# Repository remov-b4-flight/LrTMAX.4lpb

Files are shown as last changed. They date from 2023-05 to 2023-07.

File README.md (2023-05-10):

# LrTMAX.4lpb
KiCAD project of LrTMAX Print Circuit Board  
project impeoved by versions, currently 3 versions are there.  
## MicroB
It's basic functionality of LrTMAX board.  
connected to host PC with USB micro B connector.  
## type C
It changed host connectors with USB type C.  
## DFU
Add ability to use DFU bootloader by set BOOT0 signal by DIP switch.  
(No needed ST-LIMK for firmware load, use STM32programmer.)  
and changed ST-LINK connector assignment to STDC-14. (STLiNKV3-MINIE compatible)

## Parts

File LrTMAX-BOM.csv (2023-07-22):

Ref | Qnty | Value | Cmp name | Footprint
C10, C11, C12, C13, C14, C15, C16, C17, C18, C19, C20, C21, C22, C23, C24, C25, | 16 | 33n | C-Device | Capacitor_SMD:C_0805_2012Metric
C30, C31, C32, C33, C34, C35, C36, C37, C38, C55, | 10 | 100n | C-Device | Capacitor_SMD:C_0805_2012Metric
C40, C41, C43, C44, C45, | 5 | 100n | C-Device | Capacitor_SMD:C_0603_1608Metric
C42, C46, C51, C52, | 4 | 4.7u | C-Device | Capacitor_SMD:C_0805_2012Metric
C47, C48, C49, C50, C53, C54, C56, | 7 | 1u | C-Device | Capacitor_SMD:C_0805_2012Metric
D1, D2, D3, D4, D5, D6, D7, D8, D10, D11, D12, D13, D14, D15, D16, D17, | 16 | 1N4148W | 1N4148W-Diode | LrE-6:D_SOD-123
D18, | 1 | LED 0603 BLUE | LED-Device | LED_SMD:LED_0603_1608Metric
D31, D32, D33, D34, D35, D36, D37, D38, | 8 | WS2812B-2020 | WS2812B-2020 | LrE-6:LED_WS2812B-2020
J1, | 1 | USB_C_Receptacle_USB2.0 | USB_C_Receptacle_USB2.0 | Connector_USB:USB_C_Receptacle_HRO_TYPE-C-31-M-12
J2, | 1 | Conn_02x05_Odd_Even | Conn_02x05_Odd_Even | Connector_PinHeader_1.27mm:PinHeader_2x05_P1.27mm_Vertical
Q1, | 1 | 2N7002 | 2N7002-Transistor_FET | Package_TO_SOT_SMD:SOT-23
R1, R2, R3, R4, R42, | 5 | 1K | R-Device | Resistor_SMD:R_0805_2012Metric
R5, R6, | 2 | 5.1K | R-Device | Resistor_SMD:R_0805_2012Metric
R7, R10, R11, R12, R13, R14, R15, R16, R17, R18, R19, R20, R21, R22, R23, R24, R25, R40, R41, R47, | 20 | 10K | R-Device | Resistor_SMD:R_0805_2012Metric
R44, | 1 | 100 | R-Device | Resistor_SMD:R_0805_2012Metric
R45, | 1 | 62 | R-Device | Resistor_SMD:R_0805_2012Metric
R46, | 1 | 1.2K | R-Device | Resistor_SMD:R_0805_2012Metric
R48, | 1 | 470 | R-Device | Resistor_SMD:R_0805_2012Metric
SW1, SW2, SW3, SW4, SW5, SW6, SW7, SW8, | 8 | Tact_SW_8mm | SW_Push_45deg-Switch | Button_Switch_THT:SW_PUSH_6mm_H9.5mm
SW10, SW11, SW12, SW13, SW14, SW15, SW16, SW17, | 8 | EC11_SMD | Rotary_Encoder_Switch-Device | Rotary_Encoder:RotaryEncoder_Alps_EC11E-Switch_Vertical_H20mm
SW20, | 1 | SW_SPST | SW_SPST | Button_Switch_SMD:SW_DIP_SPSTx01_Slide_Copal_CHS-01B_W7.62mm_P1.27mm
TP1, | 1 | TestPoint | TestPoint-Connector | TestPoint:TestPoint_THTPad_D1.0mm_Drill0.5mm
U1, | 1 | STM32F072C8Tx | STM32F072C8Tx-MCU_ST_STM32F0 | Package_QFP:LQFP-48_7x7mm_P0.5mm
U3, | 1 | SSD1306_OLED_0.91 | OLED-0.91 | LrE-6:OLED-9.1
U4, | 1 | SPX3819M5-L3-3TR | LDK130-08_SOT23_SOT353-Regulator_Linear | Package_TO_SOT_SMD:SOT-23-5

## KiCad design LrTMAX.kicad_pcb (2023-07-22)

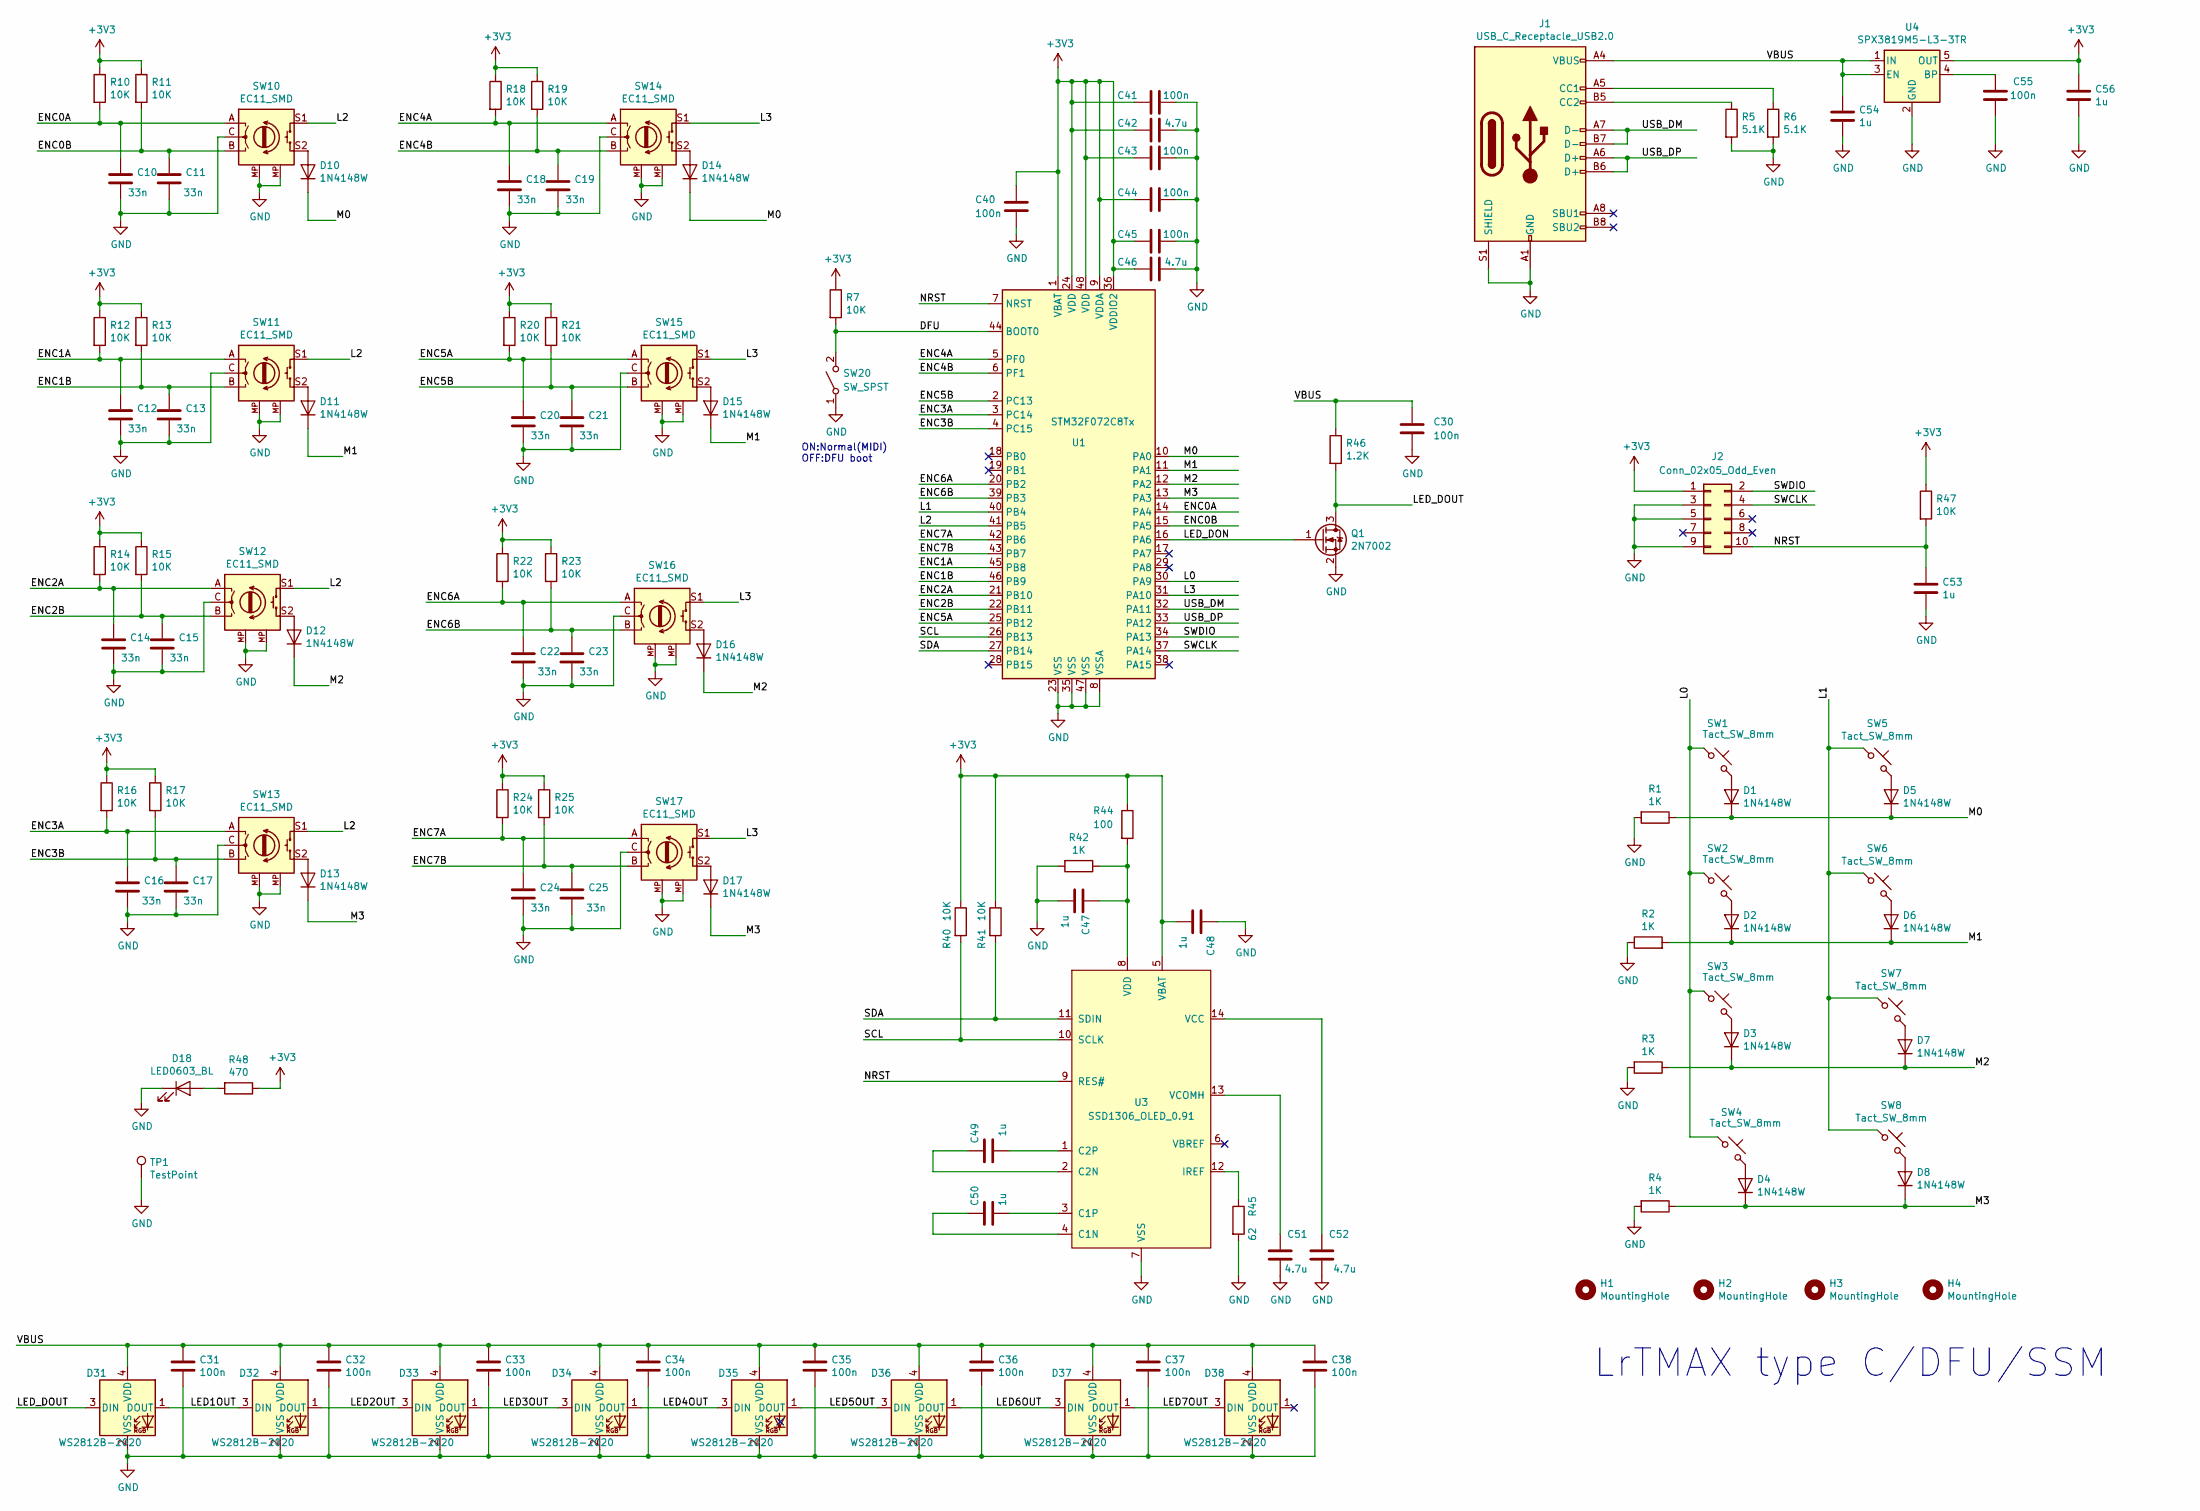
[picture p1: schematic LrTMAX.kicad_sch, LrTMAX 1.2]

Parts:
C10, C11, C12, C13, C14, C15, C16, C17, C18, C19, C20, C21, C22, C23, C24, C25: 33n; C_0805_2012Metric
C30, C31, C32, C33, C34, C35, C36, C37, C38, C55: 100n; C_0805_2012Metric
C40, C41, C43, C44, C45: 100n; C_0603_1608Metric
C42, C46, C51, C52: 4.7u; C_0805_2012Metric
C47, C48, C49, C50, C53, C54, C56: 1u; C_0805_2012Metric
D1, D2, D3, D4, D5, D6, D7, D8, D10, D11, D12, D13, D14, D15, D16, D17: 1N4148W; D_SOD-123
D18: LED0603_BL; LED_0603_1608Metric
D31, D32, D33, D34, D35, D36, D37, D38: WS2812B-2020; LED_WS2812B-2020
H1, H2, H3, H4: MountingHole; MountingHole_2.7mm_M2.5
J1: USB_C_Receptacle_USB2.0; USB_C_Receptacle_HRO_TYPE-C-31-M-12
J2: Conn_02x05_Odd_Even; PinHeader_2x05_P1.27mm_Vertical
Q1: 2N7002; SOT-23
R1, R2, R3, R4, R42: 1K; R_0805_2012Metric
R5, R6: 5.1K; R_0805_2012Metric
R7, R10, R11, R12, R13, R14, R15, R16, R17, R18, R19, R20, R21, R22, R23, R24, R25, R40, R41, R47: 10K; R_0805_2012Metric
R44: 100; R_0805_2012Metric
R45: 62; R_0805_2012Metric
R46: 1.2K; R_0805_2012Metric
R48: 470; R_0805_2012Metric
SW1, SW2, SW3, SW4, SW5, SW6, SW7, SW8: Tact_SW_8mm; SW_PUSH_6mm_H9.5mm
SW10, SW11, SW12, SW13, SW14, SW15, SW16, SW17: EC11_SMD; RotaryEncoder_Alps_EC11E-Switch_Vertical_H20mm
SW20: SW_SPST; SW_DIP_SPSTx01_Slide_Copal_CHS-01B_W7.62mm_P1.27mm
TP1: TestPoint; TestPoint_THTPad_D1.0mm_Drill0.5mm
U1: STM32F072C8Tx; LQFP-48_7x7mm_P0.5mm
U3: SSD1306_OLED_0.91; OLED-9.1
U4: SPX3819M5-L3-3TR; SOT-23-5

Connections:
+3V3: C40.1, C41.2, C42.2, C43.2, C44.2, C45.2, C46.2, C48.1, C56.1, J2.1, R7.1, R10.1, R11.1, R12.1, R13.1, R14.1, R15.1, R16.1, R17.1, R18.1, R19.1, R20.1, R21.1, R22.1, R23.1, R24.1, R25.1, R40.1, R41.1, R44.1, R47.1, R48.1, U1.1 (VBAT), U1.9 (VDDA), U1.24 (VDD), U1.36 (VDDIO2), U1.48 (VDD), U3.5 (VBAT), U4.5 (OUT)
/DFU: R7.2, SW20.2 (B), U1.44 (BOOT0)
/ENC0A: C10.1, R10.2, SW10.A, U1.14 (PA4)
/ENC0B: C11.1, R11.2, SW10.B, U1.15 (PA5)
/ENC1A: C12.1, R12.2, SW11.A, U1.45 (PB8)
/ENC1B: C13.1, R13.2, SW11.B, U1.46 (PB9)
/ENC2A: C14.1, R14.2, SW12.A, U1.21 (PB10)
/ENC2B: C15.1, R15.2, SW12.B, U1.22 (PB11)
/ENC3A: C16.1, R16.2, SW13.A, U1.3 (PC14)
/ENC3B: C17.1, R17.2, SW13.B, U1.4 (PC15)
/ENC4A: C18.1, R18.2, SW14.A, U1.5 (PF0)
/ENC4B: C19.1, R19.2, SW14.B, U1.6 (PF1)
/ENC5A: C20.1, R20.2, SW15.A, U1.25 (PB12)
/ENC5B: C21.1, R21.2, SW15.B, U1.2 (PC13)
/ENC6A: C22.1, R22.2, SW16.A, U1.20 (PB2)
/ENC6B: C23.1, R23.2, SW16.B, U1.39 (PB3)
/ENC7A: C24.1, R24.2, SW17.A, U1.42 (PB6)
/ENC7B: C25.1, R25.2, SW17.B, U1.43 (PB7)
/L0: SW1.1, SW2.1, SW3.1, SW4.1, U1.30 (PA9)
/L1: SW5.1, SW6.1, SW7.1, SW8.1, U1.40 (PB4)
/L2: SW10.S1, SW11.S1, SW12.S1, SW13.S1, U1.41 (PB5)
/L3: SW14.S1, SW15.S1, SW16.S1, SW17.S1, U1.31 (PA10)
/LED1OUT: D31.1 (DOUT), D32.3 (DIN)
/LED2OUT: D32.1 (DOUT), D33.3 (DIN)
/LED3OUT: D33.1 (DOUT), D34.3 (DIN)
/LED4OUT: D34.1 (DOUT), D35.3 (DIN)
/LED5OUT: D35.1 (DOUT), D36.3 (DIN)
/LED6OUT: D36.1 (DOUT), D37.3 (DIN)
/LED7OUT: D37.1 (DOUT), D38.3 (DIN)
/LED_DON: Q1.1 (G), U1.16 (PA6)
/LED_DOUT: D31.3 (DIN), Q1.3 (D), R46.2
/M0: D1.1 (K), D5.1 (K), D10.1 (K), D14.1 (K), R1.1, U1.10 (PA0)
/M1: D2.1 (K), D6.1 (K), D11.1 (K), D15.1 (K), R2.2, U1.11 (PA1)
/M2: D3.1 (K), D7.1 (K), D12.1 (K), D16.1 (K), R3.1, U1.12 (PA2)
/M3: D4.1 (K), D8.1 (K), D13.1 (K), D17.1 (K), R4.1, U1.13 (PA3)
/NRST: C53.1, J2.10, R47.2, U1.7 (NRST), U3.9 (RES#)
/SCL: R40.2, U1.26 (PB13), U3.10 (SCLK)
/SDA: R41.2, U1.27 (PB14), U3.11 (SDIN)
/SWCLK: J2.4, U1.37 (PA14)
/SWDIO: J2.2, U1.34 (PA13)
/USB_DM: J1.A7 (D-), J1.B7 (D-), U1.32 (PA11)
/USB_DP: J1.A6 (D+), J1.B6 (D+), U1.33 (PA12)
/VBUS: C30.1, C31.1, C32.1, C33.1, C34.1, C35.1, C36.1, C37.1, C38.1, C54.1, D31.4 (VDD), D32.4 (VDD), D33.4 (VDD), D34.4 (VDD), D35.4 (VDD), D36.4 (VDD), D37.4 (VDD), D38.4 (VDD), J1.A4 (VBUS), J1.A9 (VBUS), J1.B4 (VBUS), J1.B9 (VBUS), R46.1, U4.1 (IN), U4.3 (EN)
GND: C10.2, C11.2, C12.2, C13.2, C14.2, C15.2, C16.2, C17.2, C18.2, C19.2, C20.2, C21.2, C22.2, C23.2, C24.2, C25.2, C30.2, C31.2, C32.2, C33.2, C34.2, C35.2, C36.2, C37.2, C38.2, C40.2, C41.1, C42.1, C43.1, C44.1, C45.1, C46.1, C47.1, C48.2, C51.1, C52.1, C53.2, C54.2, C55.2, C56.2, D18.1 (K), D31.2 (VSS), D32.2 (VSS), D33.2 (VSS), D34.2 (VSS), D35.2 (VSS), D36.2 (VSS), D37.2 (VSS), D38.2 (VSS), J1.A1 (GND), J1.A12 (GND), J1.B1 (GND), J1.B12 (GND), J1.S1 (SHIELD), J2.3, J2.5, J2.9, Q1.2 (S), R1.2, R2.1, R3.2, R4.2, R5.2, R6.2, R42.2, R45.2, SW10.C, SW10.MP (GND), SW11.C, SW11.MP (GND), SW12.C, SW12.MP (GND), SW13.C, SW13.MP (GND), SW14.C, SW14.MP (GND), SW15.C, SW15.MP (GND), SW16.C, SW16.MP (GND), SW17.C, SW17.MP (GND), SW20.1 (A), TP1.1, U1.8 (VSSA), U1.23 (VSS), U1.35 (VSS), U1.47 (VSS), U3.7 (VSS), U4.2 (GND)
unnamed: C47.2, R42.1, R44.2, U3.8 (VDD)
unnamed: C49.1, U3.2 (C2N)
unnamed: C49.2, U3.1 (C2P)
unnamed: C50.1, U3.4 (C1N)
unnamed: C50.2, U3.3 (C1P)
unnamed: C51.2, U3.13 (VCOMH)
unnamed: C52.2, U3.14 (VCC)
unnamed: C55.1, U4.4 (BP)
unnamed: D1.2 (A), SW1.2
unnamed: D2.2 (A), SW2.2
unnamed: D3.2 (A), SW3.2
unnamed: D4.2 (A), SW4.2
unnamed: D5.2 (A), SW5.2
unnamed: D6.2 (A), SW6.2
unnamed: D7.2 (A), SW7.2
unnamed: D8.2 (A), SW8.2
unnamed: D10.2 (A), SW10.S2
unnamed: D11.2 (A), SW11.S2
unnamed: D12.2 (A), SW12.S2
unnamed: D13.2 (A), SW13.S2
unnamed: D14.2 (A), SW14.S2
unnamed: D15.2 (A), SW15.S2
unnamed: D16.2 (A), SW16.S2
unnamed: D17.2 (A), SW17.S2
unnamed: D18.2 (A), R48.2
unnamed: J1.A5 (CC1), R6.1
unnamed: J1.B5 (CC2), R5.1
unnamed: R45.1, U3.12 (IREF)

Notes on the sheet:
LrTMAX type C/DFU/SSM
ON:Normal(MIDI) OFF:DFU boot

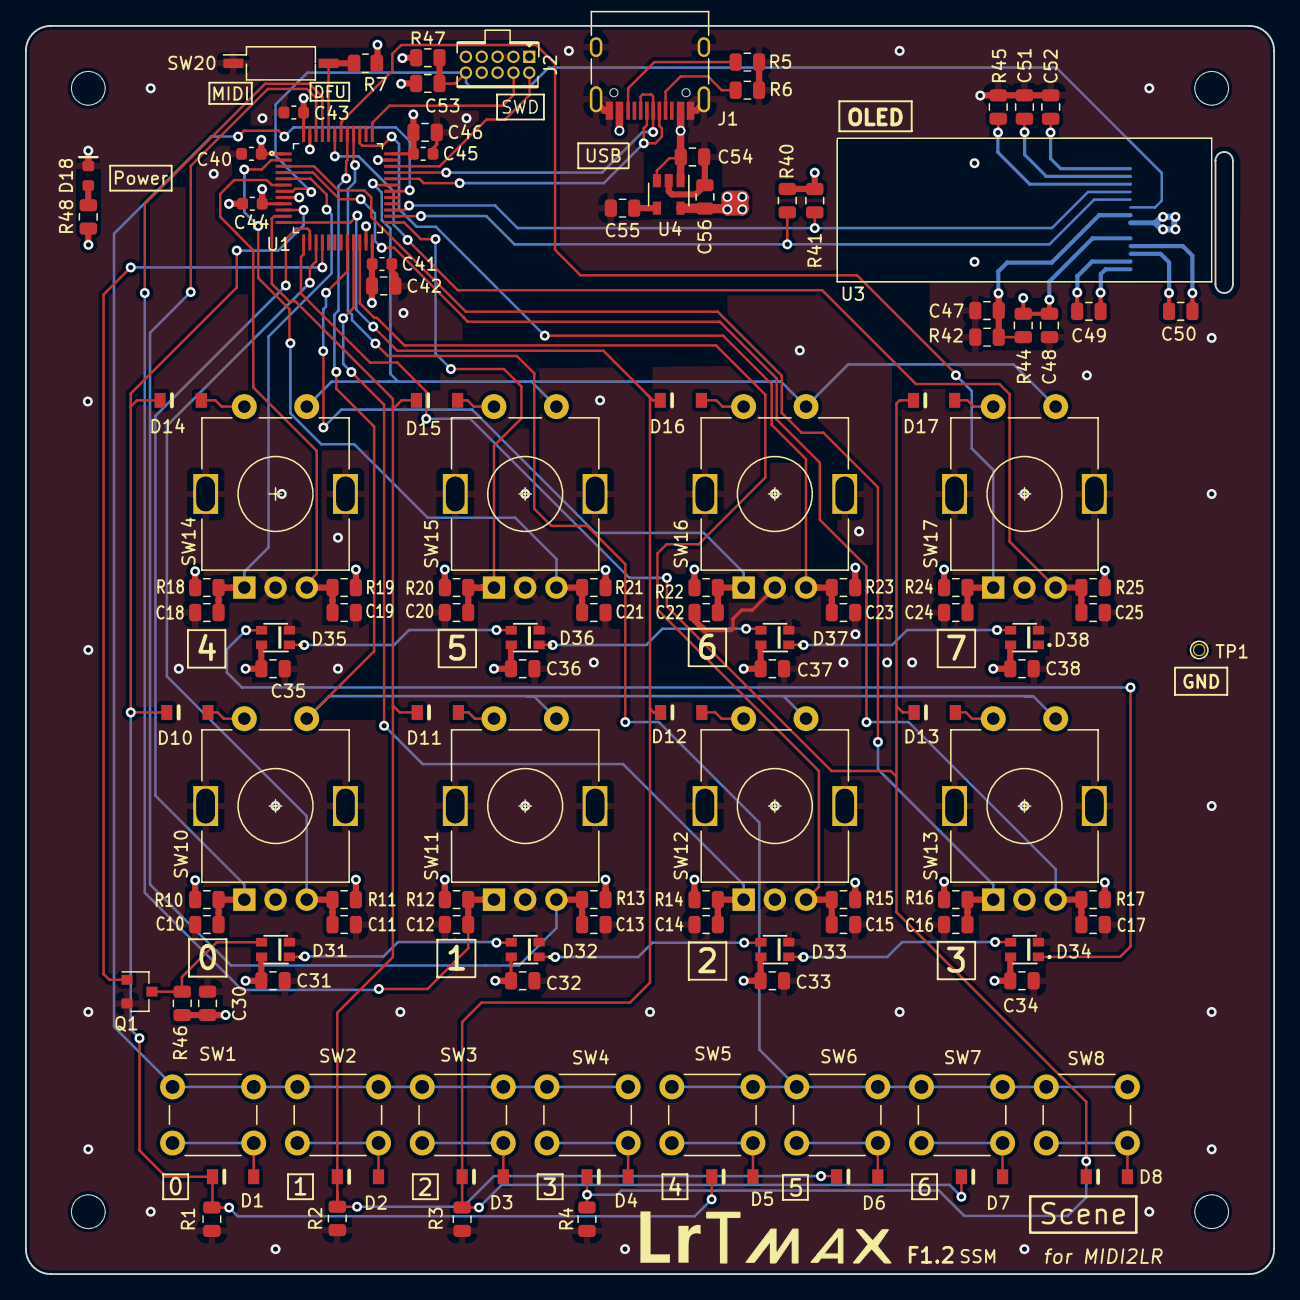
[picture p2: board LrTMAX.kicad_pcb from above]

Board: 4 copper layers, 100.0 x 100.0 mm, 126 parts (0 on the bottom side), 72 nets.

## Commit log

2021-05-24 1st Commit
    [LrE-6.dsn, LrTMAX.kicad_pcb, LrTMAX.sch]
2021-05-25 Fix panels
    [LrTMAX.kicad_pcb]
2021-05-30 Board fixes
    [LrTMAX.kicad_pcb]
2021-06-04 Board fix
    [LrTMAX.kicad_pcb]
2021-06-06 fix typo
    [LrTMAX.kicad_pcb]
2021-06-12 Add BOM
    [LrTMAX.BOM.csv]
2021-06-20 0.46-1
    Reflact board debug.
    [LrTMAX.kicad_pcb]
2021-06-28 0.46-3
    Adjust LED PWM width to meed WS2812-2020 spec.
    [LrTMAX.BOM.csv, LrTMAX.sch]
2021-07-03 0.46-4
    Fix EXTI routine for ENC3.
    (and first modify for F1.2 board)
    [LrTMAX.kicad_pcb]
2021-07-05 0.46-6
    LrTMAX.4lpb modify.
    [LrTMAX.BOM.csv, LrTMAX.kicad_pcb]
2021-07-06 0.46-6
    Board F1.2 order.
    [LrTMAX.kicad_pcb]
2021-07-12 0.47-5
    some Debug tweak.
    [LrTMAX.BOM.csv, LrTMAX.sch]
2021-08-15 0.48-4
    Adjust LED pink color.
    [LrTMAX.BOM.csv]
2021-10-07 0.49-pre6m
    move to F0_11.3
    [LrTMAX.BOM.csv, LrTMAX.kicad_pcb, LrTMAX.sch]
2021-10-14 0.49c
    USB conn. changed to typeC
    [LrTMAX.kicad_pcb, LrTMAX.sch]
2021-10-21 0.49c-3
    KiCAD library resrore & ENC5 ISR routine.
    [LrTMAX.BOM.csv, LrTMAX.sch]
2021-11-14 0.55-pre3
    Fix de-chatter cap. values to 22nF -> 100nF
    [LrTMAX.BOM.csv, LrTMAX.sch]
2021-12-15 0.55-10
    Function assign modification Scene0 A6,A7 as quick development.
    Revert back 'connect indication' by setup packet id received.
    [LrTMAX.BOM.csv]
2021-12-16 0.55-11
    Fix optimize level = 2
    [LrTMAX.BOM.csv]
2022-07-11 0.59-22
    reverse de-chattter cap. to 22n
    [LrTMAX.BOM.csv, LrTMAX.sch]
2023-01-28 0.62-00
    add kicad 6.0 pattern to LrTMAX.l4pb/gitignore
2023-01-30 0.62-00.12cc
    Modify "BOOT0" connection on PCB as "1.2cc"
    [LrTMAX.BOM.csv, LrTMAX.kicad_pcb, LrTMAX.sch]
2023-03-22 replace SWD to 10p header
    [LrTMAX.kicad_pcb, LrTMAX.kicad_sch]
2023-03-23 Added DFU DIP Switch.
    [LrTMAX.kicad_pcb, LrTMAX.kicad_sch]
2023-03-26 Refine pattern.
    [LrTMAX.kicad_pcb]
2023-03-26 Flex wire hall refined
    [LrTMAX.kicad_pcb, LrTMAX.kicad_sch]
2023-03-26 Fix BOM .csv file.
    [LrTMAX.BOM.csv, LrTMAX.sch]
2023-04-04 modify PCB BOM for JLCPCB Asslembly order(just a test)
    [LrTMAX.BOM.csv]
2023-07-12 trace drawn except CPU.
    [LrTMAX.kicad_pcb, LrTMAX.kicad_sch]
2023-07-13 Auto routing completed and some adjustments.
    [LrE-6.dsn, LrTMAX.kicad_pcb]
2023-07-14 pattern completed
    [LrTMAX.kicad_pcb]
2023-07-15 change schematic 0.1->100n
    [LrTMAX.BOM.csv, LrTMAX.kicad_sch]
2023-07-15 change bom only.
    [LrTMAX.BOM.csv]
2023-07-15 modify BOM
    [LrTMAX.BOM.csv]
2023-07-21 some pattern/sylk refinement
    [LrTMAX-BOM.csv, LrTMAX.kicad_pcb, LrTMAX.kicad_sch]
2023-07-22 1.2SSM board ordered
    [LrTMAX-BOM.csv, LrTMAX.kicad_pcb]
